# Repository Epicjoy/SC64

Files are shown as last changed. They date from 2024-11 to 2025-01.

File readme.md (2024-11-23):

# SummerCart64 - a fully open source N64 flashcart

This project's hardware and casing are modified based on the [SummerCart64](https://github.com/Polprzewodnikowy/SummerCart64) project.

### Description

Experience classic gaming in a new way! SummerCart64 is a fully open-source flash cartridge designed for the Nintendo 64 (N64), perfect for both gamers and developers. Whether you want to relive your childhood memories or develop your own homebrew games, SummerCart64 has you covered.

### Features

-   **Extremely high game compatibility:** Supports N64 games up to 64MB (512Mb), covering the entire N64 game library
-  **Fast I/O**: Supports fast data transfer to ensure smooth gaming experiences，Thanks to a peak transfer rate of approximately 23.8 MiB/s, loading a maximum size game of **64MB** (512Mb) takes roughly 2.7 seconds under optimal conditions
- **RTC Functionality**: Built-in Real-Time Clock (**RTC**) to support games that require time functions.
-  **High-Capacity SD Card Support**: Supports microSD cards up to 2TB, allowing you to store more games and files.
-  **64DD Hardware Emulation**: It can play disk dumps directly! Combo games (N64 cartridge + 64DD disk) and multi-disk 64DD games are also supported.
- **Automatic Save Backup**: Automatically backs up saves during gameplay to protect your progress.
-  **Multi-Region Support**: Compatible with all region N64 consoles, eliminating region lock concerns.
-  **Enough space for your ROMs**: Equipped with **64 MiB SDRAM** and **16 MiB flash** memory to ensure smooth game operation.
-  **Easy Game Management**: Browse, run, and manage your game library directly on your N64 console with the intuitive N64FlashcartMenu.
-  **Full control of boot process:** perfect for trying out custom **IPL3** replacements giving you control right after N64 boots up

### Example

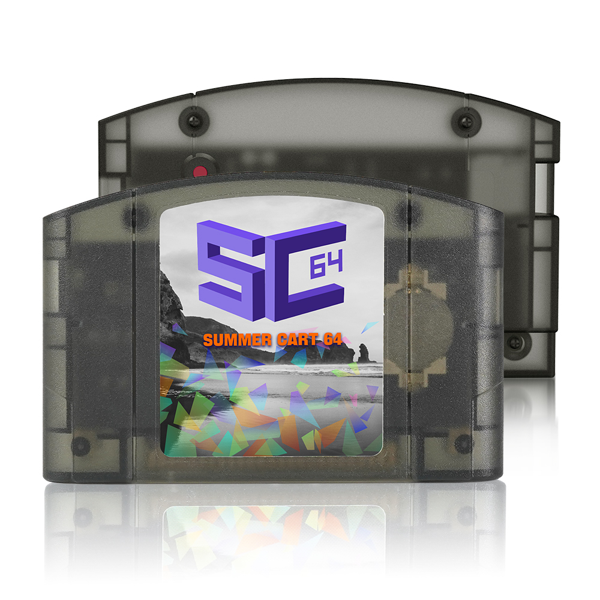
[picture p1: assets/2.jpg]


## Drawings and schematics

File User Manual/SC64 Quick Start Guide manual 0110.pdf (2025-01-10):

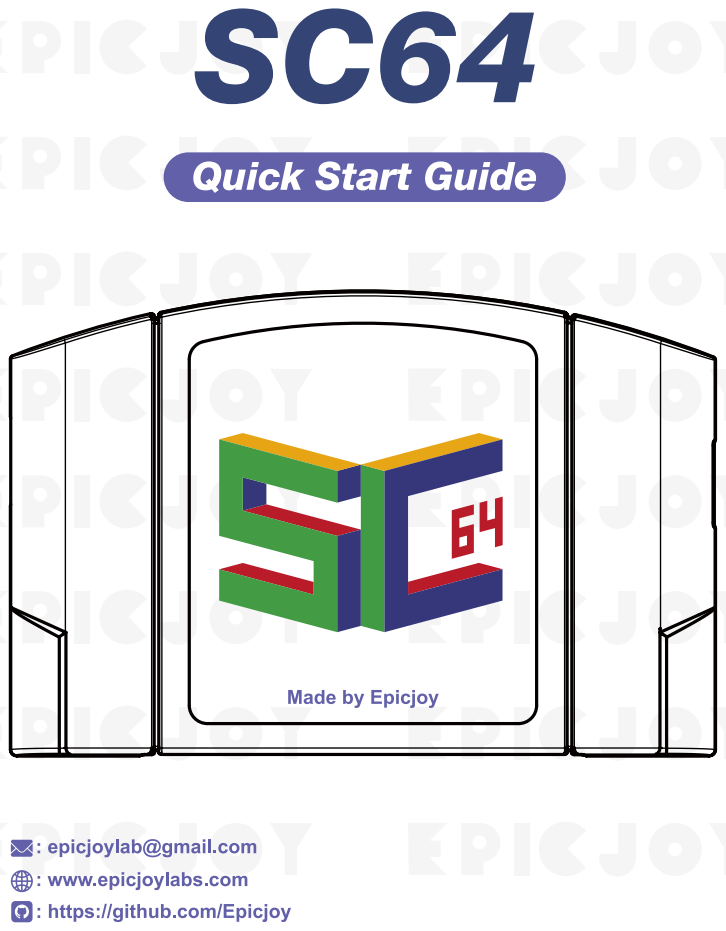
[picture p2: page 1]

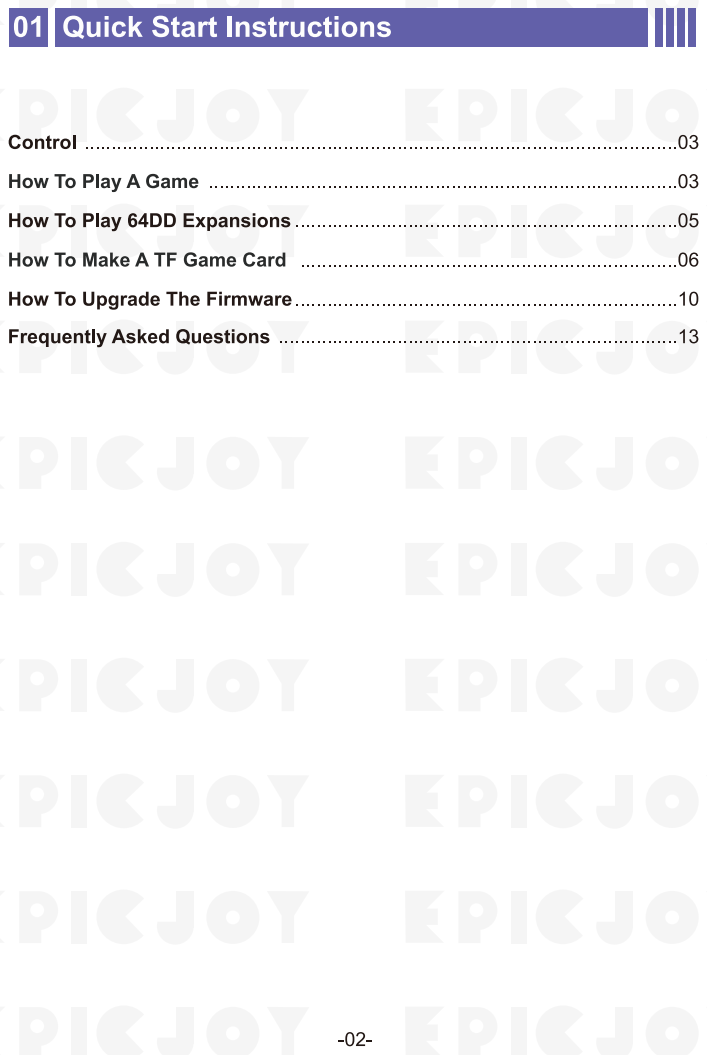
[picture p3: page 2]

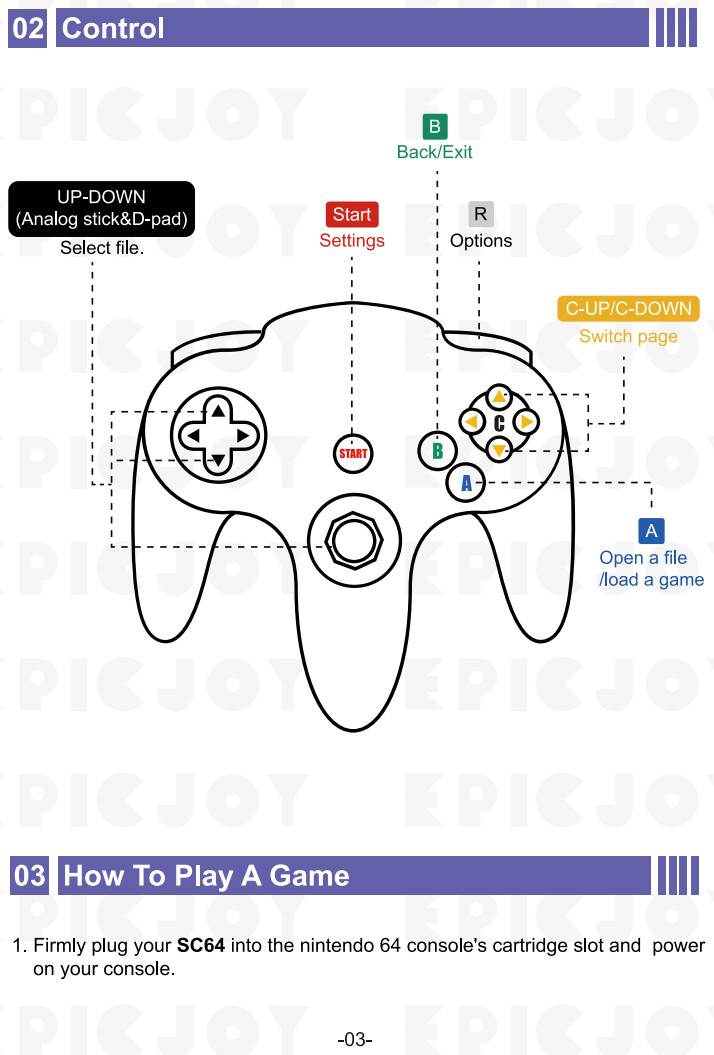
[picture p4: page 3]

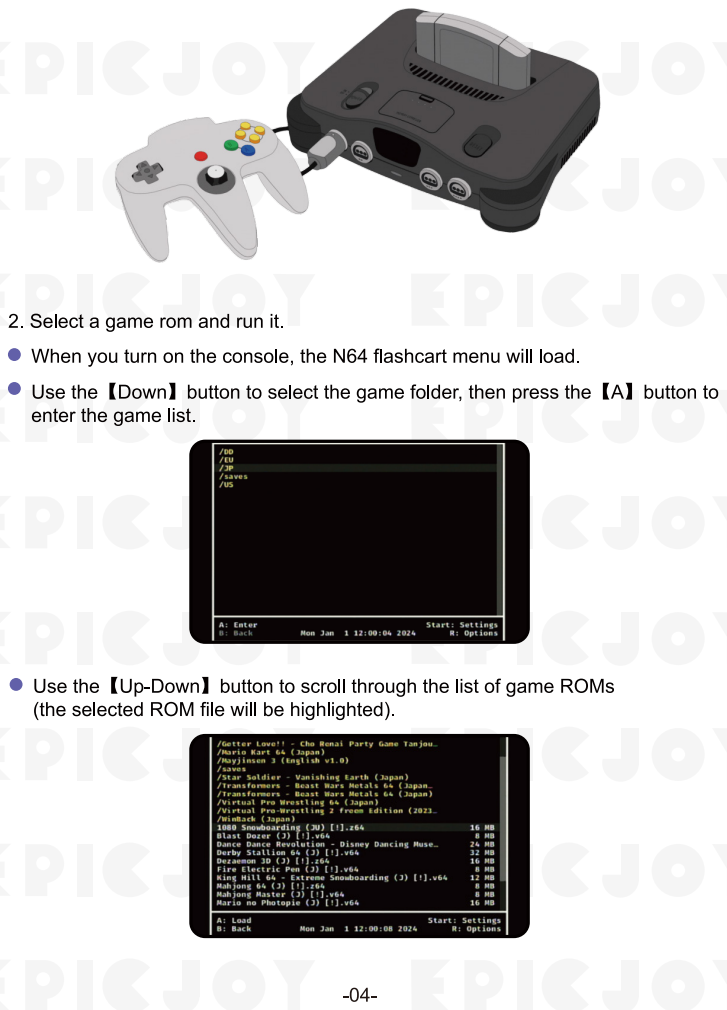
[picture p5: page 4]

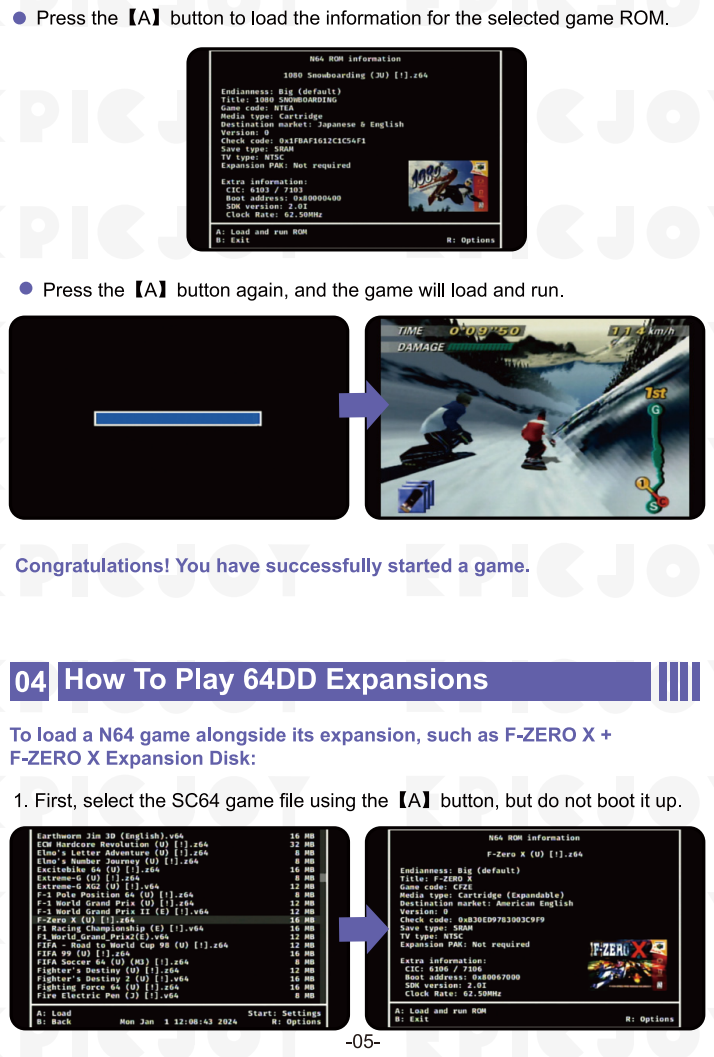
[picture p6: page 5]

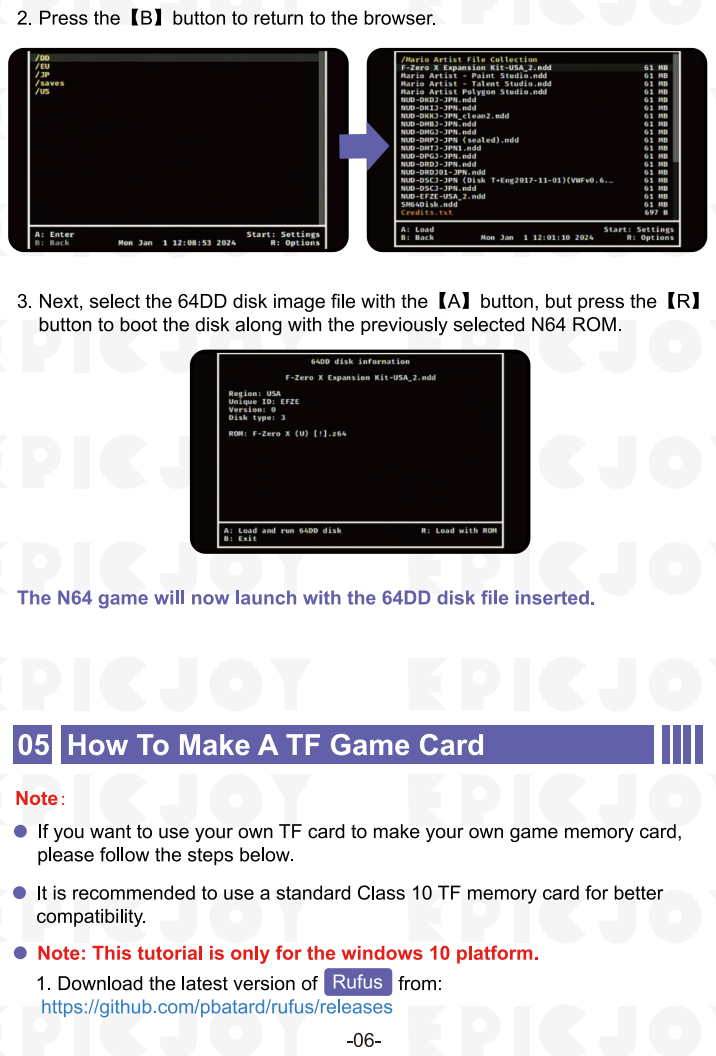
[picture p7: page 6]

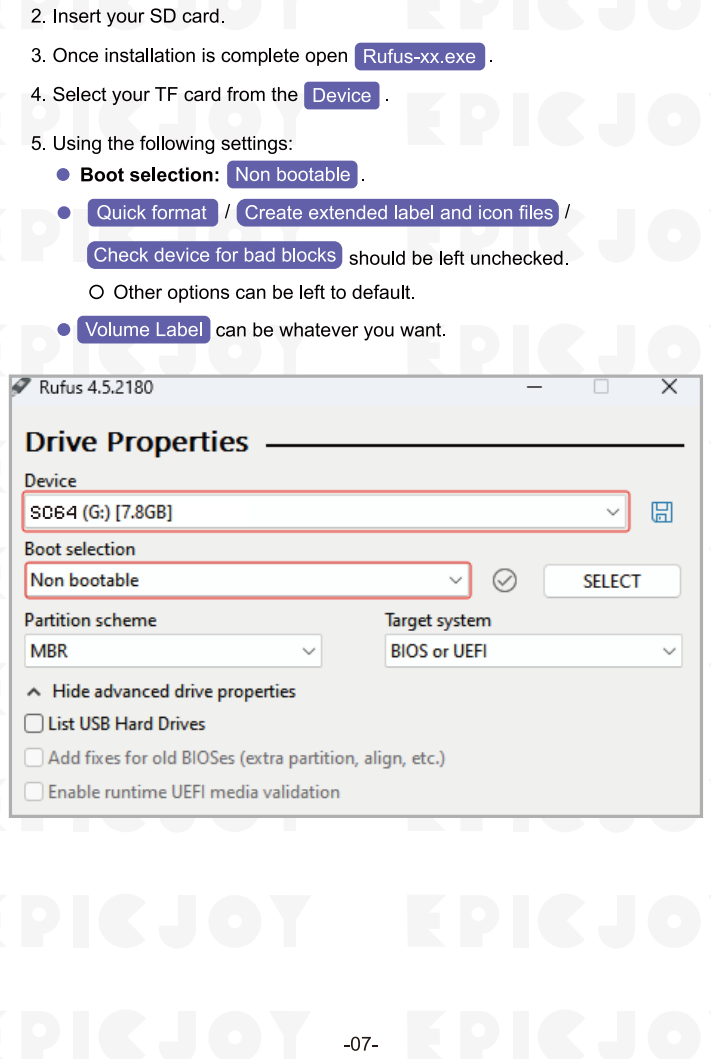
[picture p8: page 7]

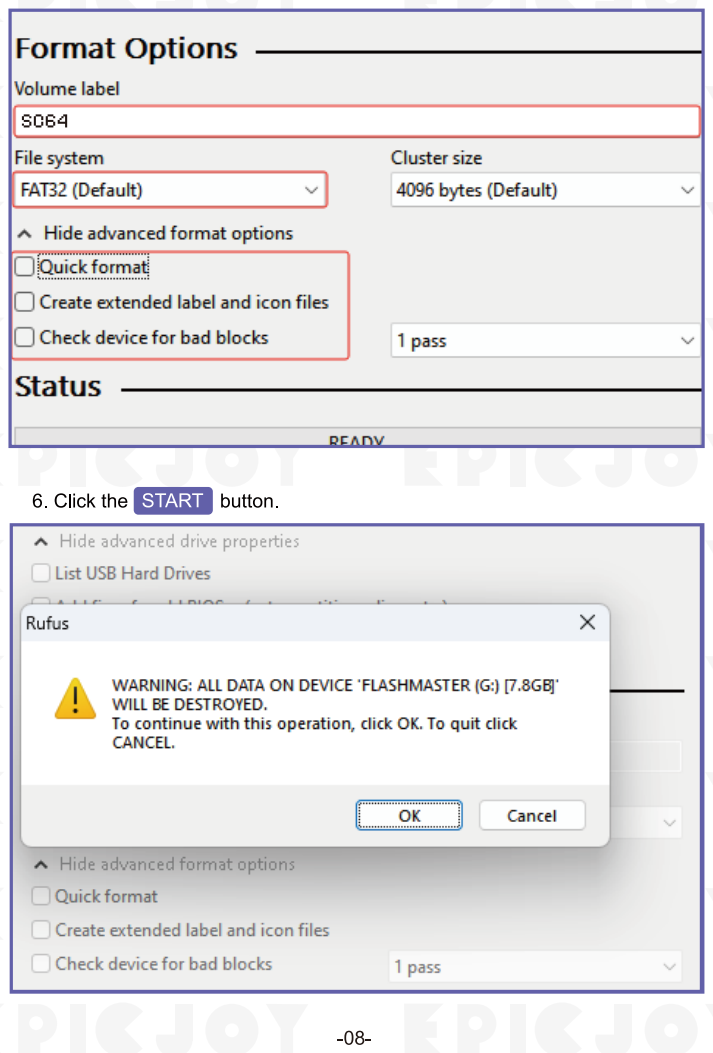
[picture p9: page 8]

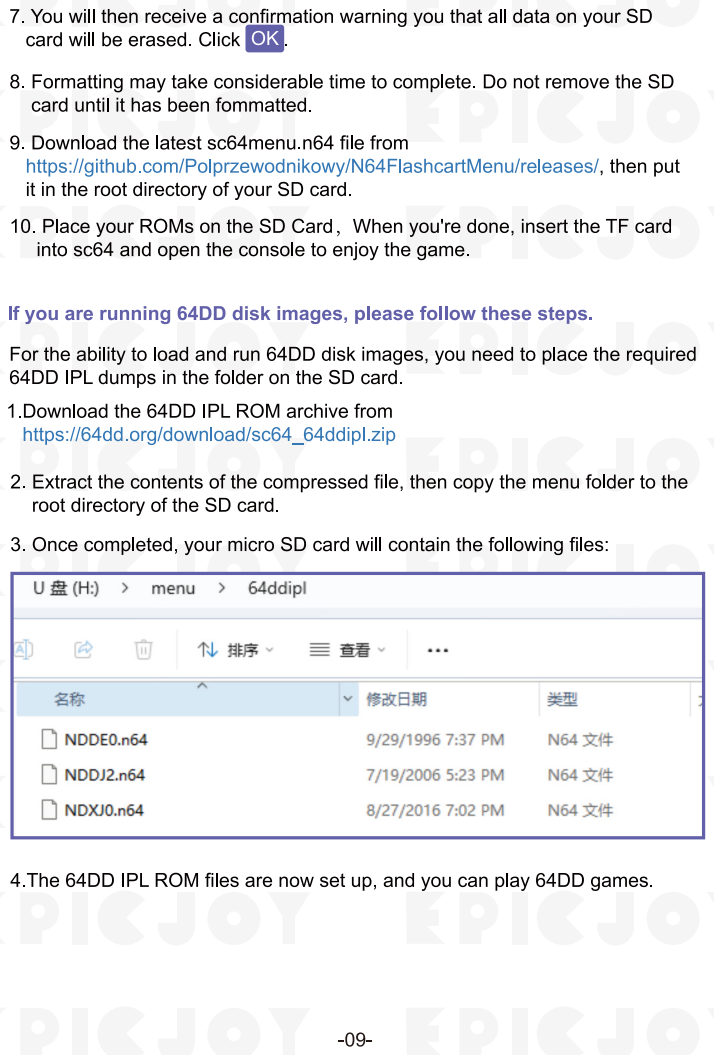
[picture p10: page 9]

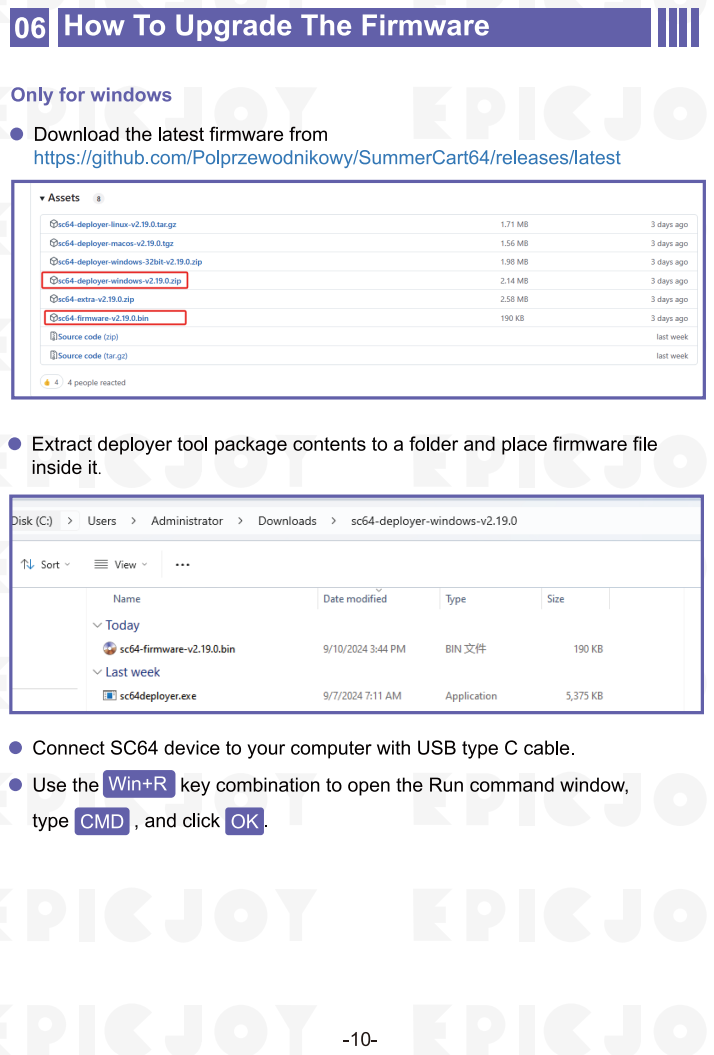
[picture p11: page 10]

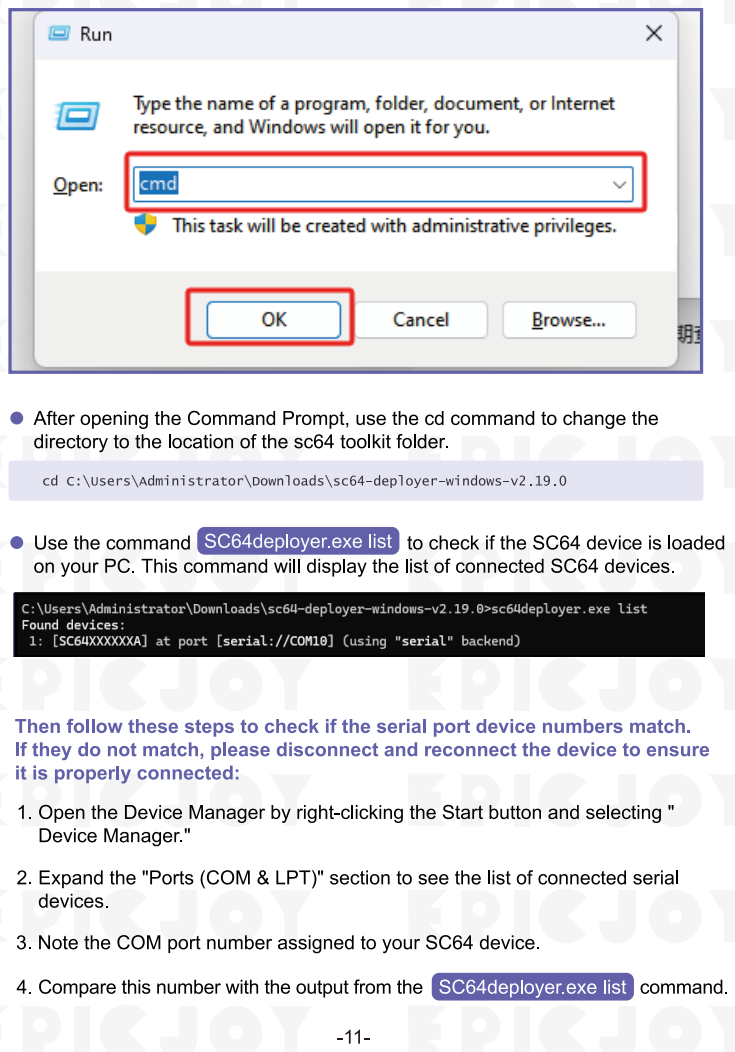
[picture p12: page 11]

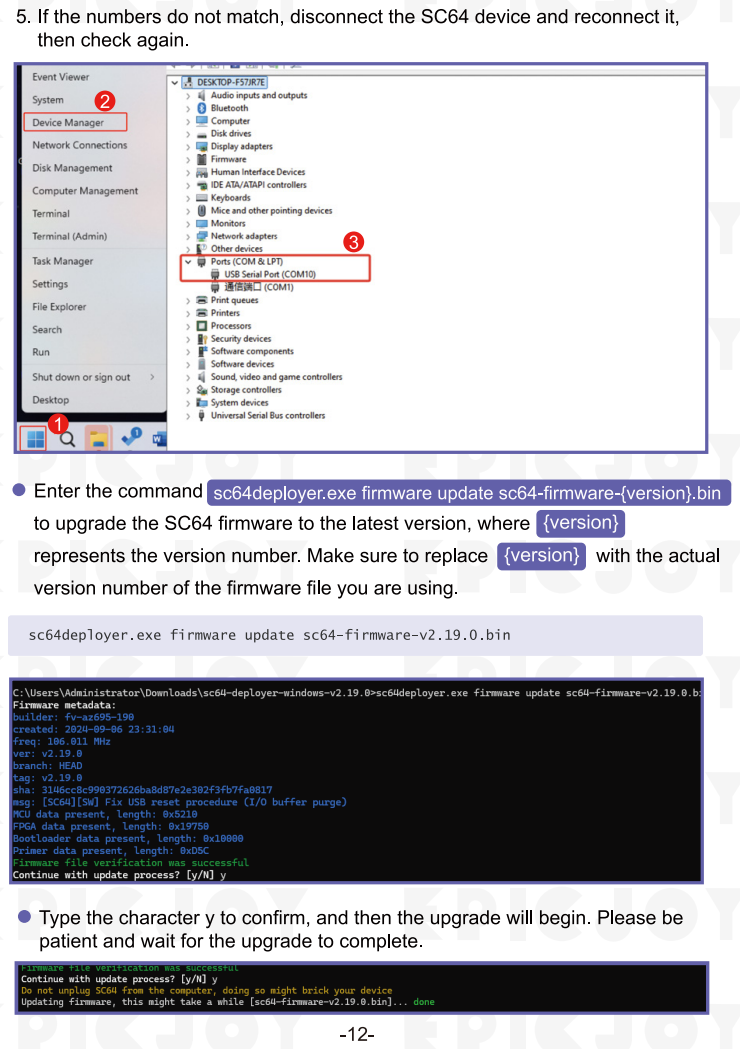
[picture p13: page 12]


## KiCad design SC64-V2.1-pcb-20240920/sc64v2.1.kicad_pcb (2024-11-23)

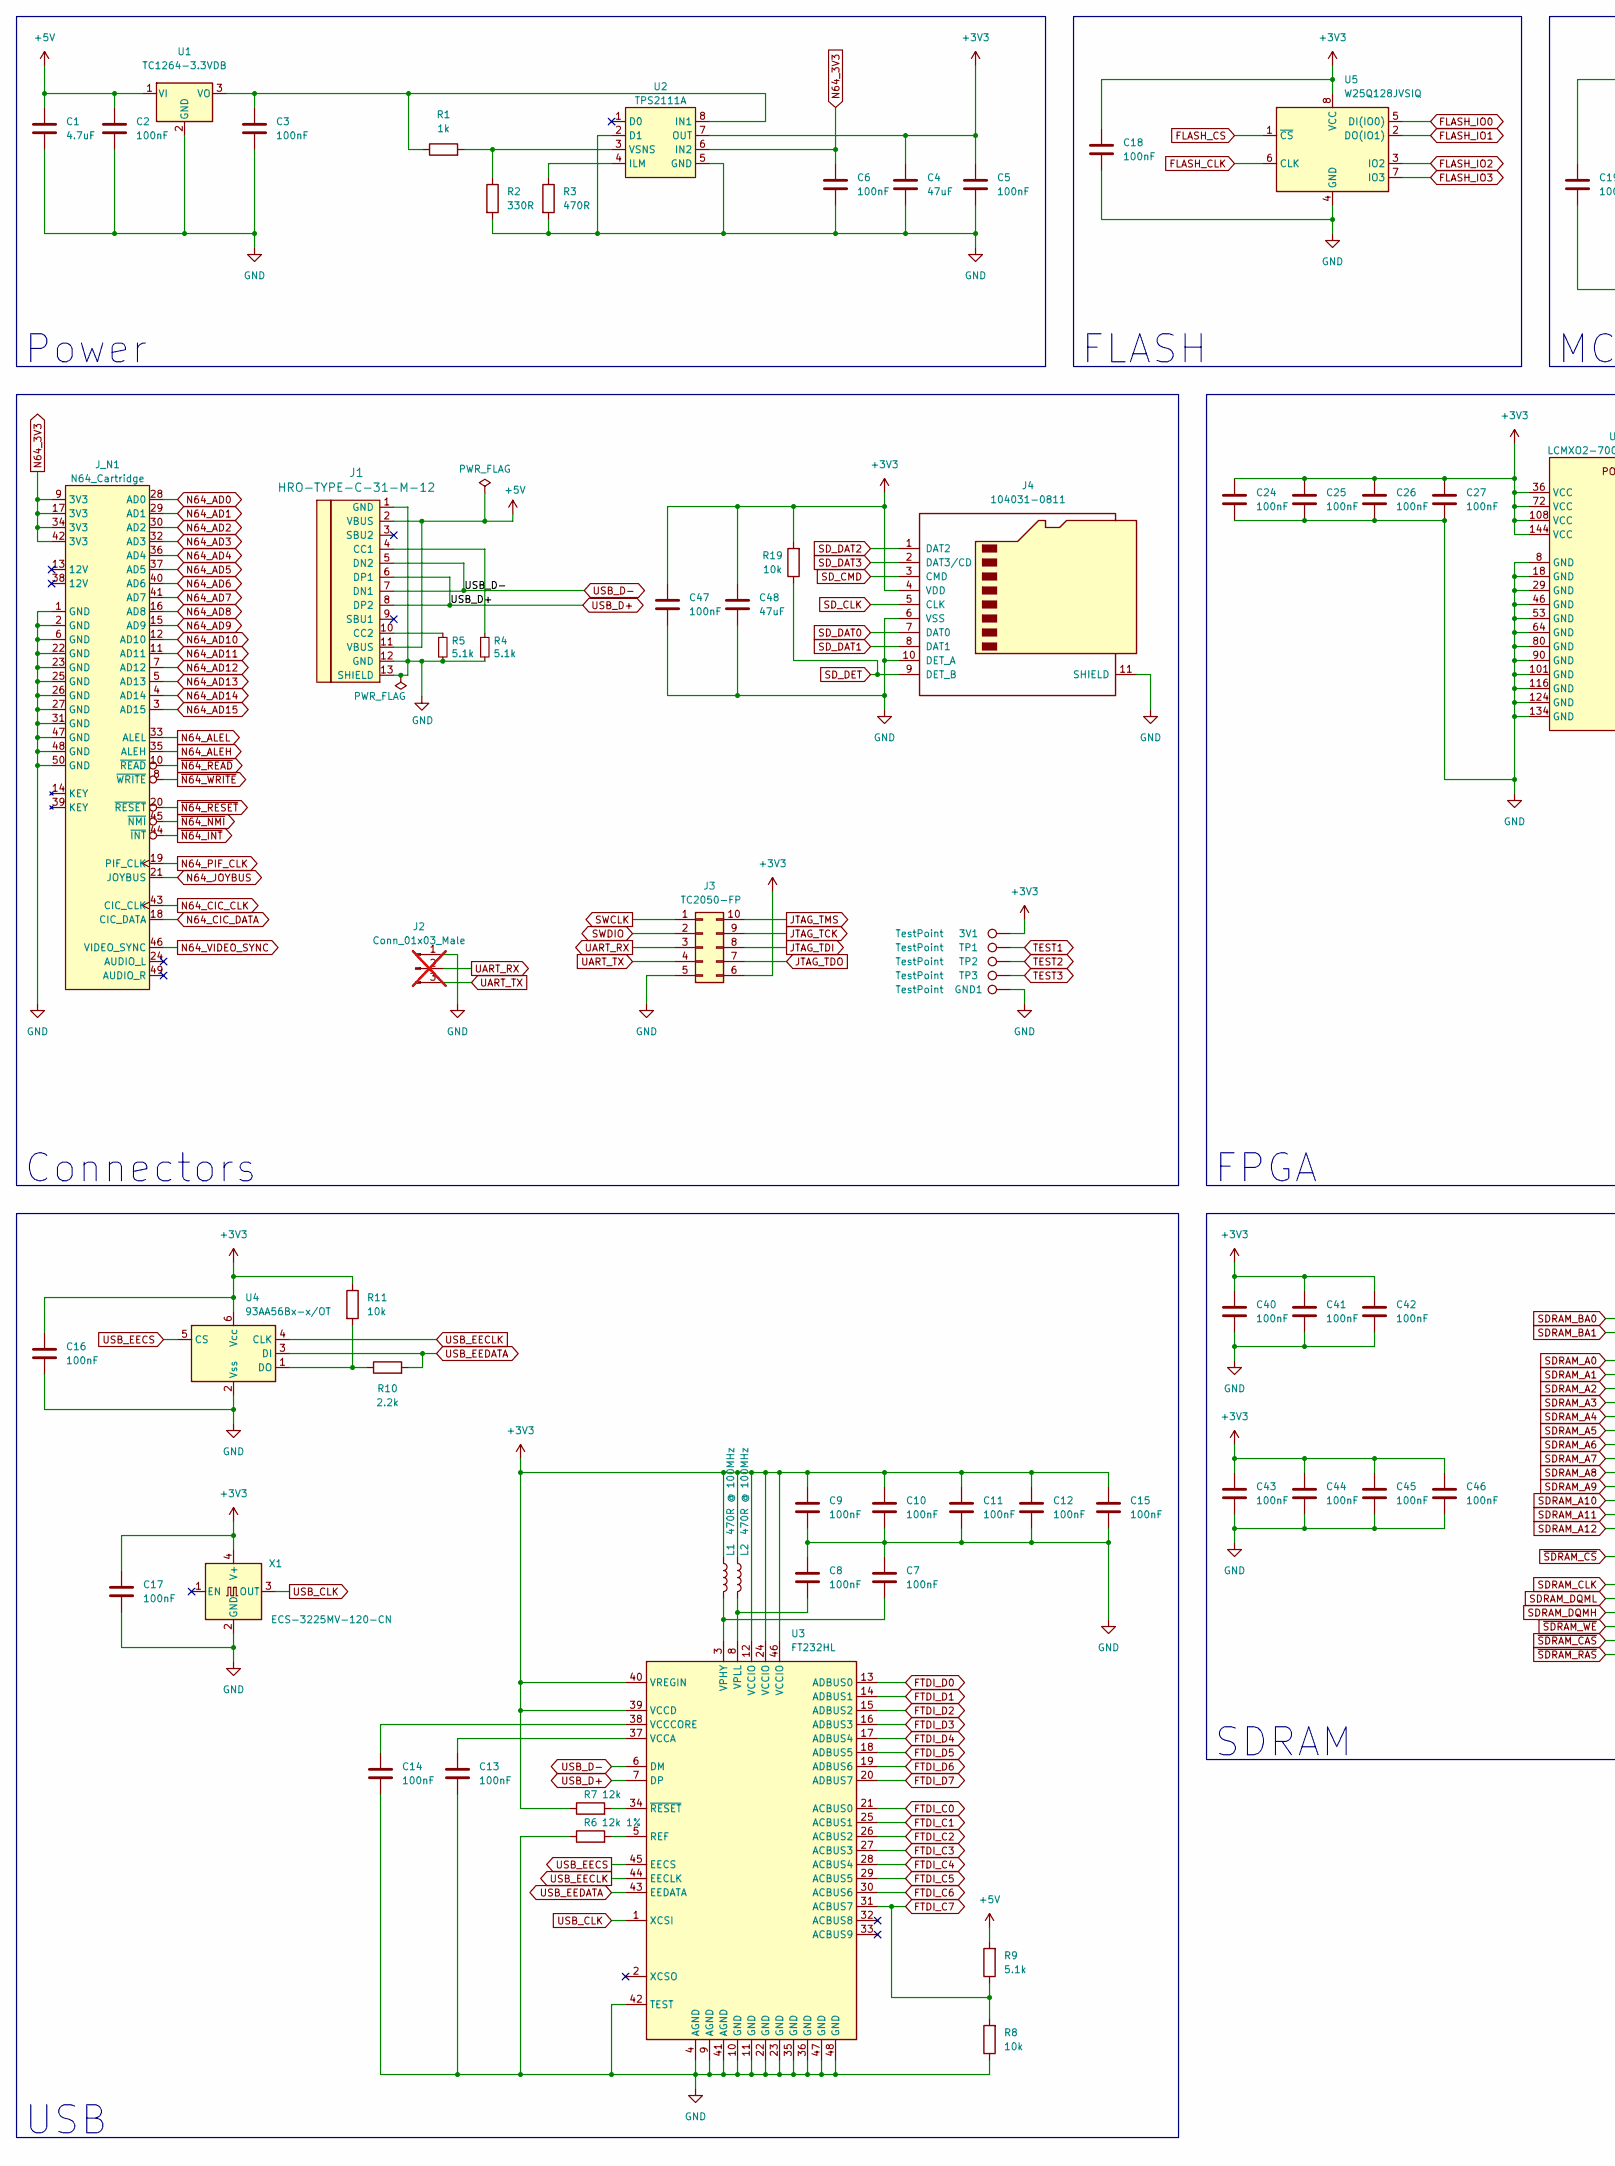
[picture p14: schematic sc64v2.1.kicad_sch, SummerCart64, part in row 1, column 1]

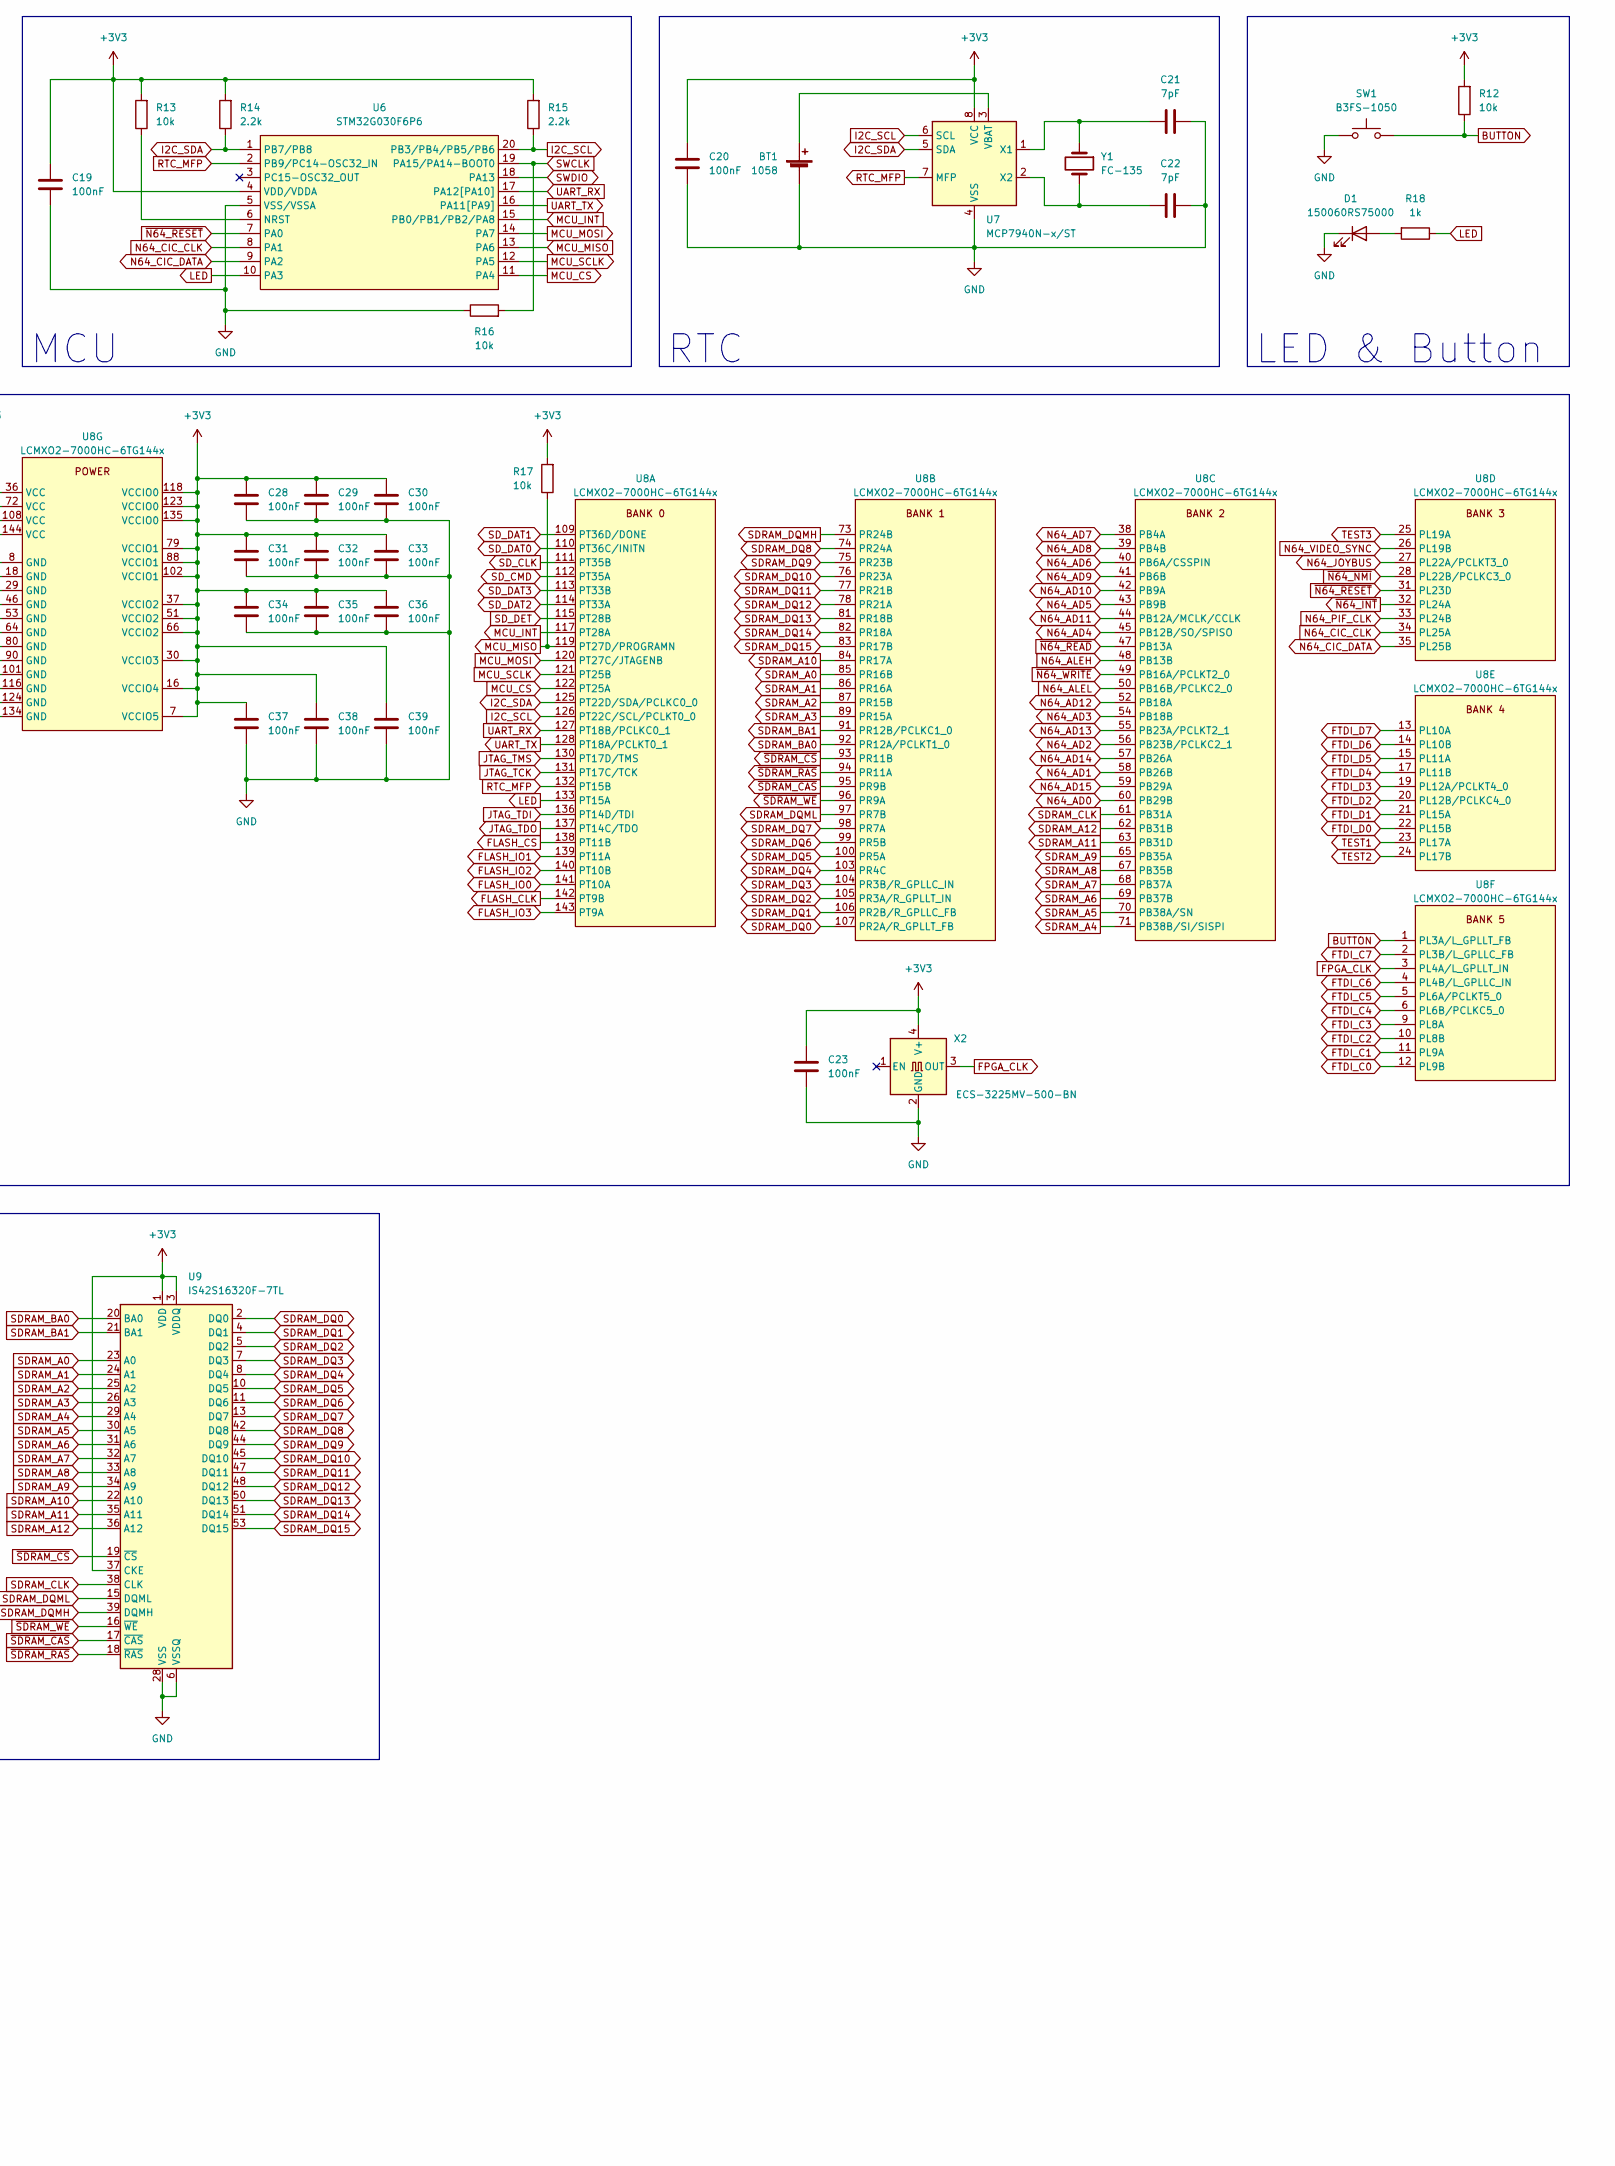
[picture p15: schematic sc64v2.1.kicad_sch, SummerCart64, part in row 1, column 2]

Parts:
3V1: TestPoint; TestPoint_Pad_D1.5mm
BT1: 1058; BatteryHolder_Keystone_1058_1x2032
C1: 4.7uF; C_0603_1608Metric
C2, C3, C5, C6, C7, C8, C9, C10, C11, C12, C13, C14, C15, C16, C17, C18, C19, C20, C23, C24, C25, C26, C27, C28, C29, C30, C31, C32, C33, C34, C35, C36, C37, C38, C39, C40, C41, C42, C43, C44, C45, C46, C47: 100nF; C_0603_1608Metric
C4, C48: 47uF; C_0805_2012Metric
C21, C22: 7pF; C_0603_1608Metric
D1: 150060RS75000; LED_0603_1608Metric
GND1: TestPoint; TestPoint_Pad_D1.5mm
J1: HRO-TYPE-C-31-M-12; HRO-TYPE-C-31-M-12-Assembly; LCSC C165948
J2: Conn_01x03_Male; PinHeader_1x03_P2.54mm_Vertical; not fitted
J3: TC2050-FP; Tag-Connect_TC2050-IDC-FP_2x05_P1.27mm_Vertical
J4: 104031-0811; microSD_HC_Molex_104031-0811
J_N1: N64_Cartridge; N64_Edge
L1, L2: 470R @ 100MHz; L_0603_1608Metric
R1, R18: 1k; R_0603_1608Metric
R2: 330R; R_0603_1608Metric
R3: 470R; R_0603_1608Metric
R4, R5: 5.1k; R_0603_1608Metric; LCSC C25905
R6: 12k 1%; R_0603_1608Metric
R7: 12k; R_0603_1608Metric
R8, R11, R12, R13, R16, R17, R19: 10k; R_0603_1608Metric
R9: 5.1k; R_0603_1608Metric
R10, R14, R15: 2.2k; R_0603_1608Metric
SW1: B3FS-1050; SW_SPST_Omron_B3FS-105xP
TP1, TP2, TP3: TestPoint; TestPoint_Pad_D1.5mm
U1: TC1264-3.3VDB; SOT-223-3_TabPin2
U2: TPS2111A; TSSOP-8_4.4x3mm_P0.65mm
U3: FT232HL; LQFP-48_7x7mm_P0.5mm
U4: 93AA56Bx-x/OT; SOT-23-6
U5: W25Q128JVSIQ; SOIC-8_5.23x5.23mm_P1.27mm
U6: STM32G030F6P6; TSSOP-20_4.4x6.5mm_P0.65mm
U7: MCP7940N-x/ST; TSSOP-8_4.4x3mm_P0.65mm
U8: LCMXO2-7000HC-6TG144x; TQFP-144_20x20mm_P0.5mm
U9: IS42S16320F-7TL; TSOP-II-54_22.2x10.16mm_P0.8mm
X1: ECS-3225MV-120-CN; Oscillator_SMD_SeikoEpson_SG8002CE-4Pin_3.2x2.5mm
X2: ECS-3225MV-500-BN; Oscillator_SMD_SeikoEpson_SG8002CE-4Pin_3.2x2.5mm
Y1: FC-135; Crystal_SMD_3215-2Pin_3.2x1.5mm

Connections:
+3V3: 3V1.1, C4.1, C5.1, C9.1, C10.1, C11.1, C12.1, C15.1, C16.2, C17.1, C18.1, C19.1, C20.1, C23.1, C24.1, C25.1, C26.1, C27.1, C28.1, C29.1, C30.1, C31.1, C32.1, C33.1, C34.1, C35.1, C36.1, C37.1, C38.1, C39.1, C40.1, C41.1, C42.1, C43.1, C44.1, C45.1, C46.1, C47.1, C48.1, J3.6, J4.4 (VDD), L1.1, L2.1, R7.1, R11.1, R12.2, R13.2, R14.2, R15.2, R17.2, R19.2, U2.7 (OUT), U3.12 (VCCIO), U3.24 (VCCIO), U3.39 (VCCD), U3.40 (VREGIN), U3.46 (VCCIO), U4.6 (Vсс), U5.8 (VCC), U6.4 (VDD/VDDA), U7.8 (VCC), U8.7 (VCCIO5), U8.16 (VCCIO4), U8.30 (VCCIO3), U8.36 (VCC), U8.37 (VCCIO2), U8.51 (VCCIO2), U8.66 (VCCIO2), U8.72 (VCC), U8.79 (VCCIO1), U8.88 (VCCIO1), U8.102 (VCCIO1), U8.108 (VCC), U8.118 (VCCIO0), U8.123 (VCCIO0), U8.135 (VCCIO0), U8.144 (VCC), U9.1 (VDD), U9.3 (VDDQ), U9.9 (VDDQ), U9.14 (VDD), U9.27 (VDD), U9.37 (CKE), U9.43 (VDDQ), U9.49 (VDDQ), X1.4 (V+), X2.4 (V+)
+5V: C1.1, C2.1, J1.2 (VBUS), J1.11 (VBUS), R9.2, U1.1 (VI)
BUTTON: R12.1, SW1.2, U8.1 (PL3A/L_GPLLT_FB)
FLASH_CLK: U5.6 (CLK), U8.142 (PT9B)
FLASH_CS: U5.1 (~CS), U8.138 (PT11B)
FLASH_IO0: U5.5 (DI(IO0)), U8.141 (PT10A)
FLASH_IO1: U5.2 (DO(IO1)), U8.139 (PT11A)
FLASH_IO2: U5.3 (IO2), U8.140 (PT10B)
FLASH_IO3: U5.7 (IO3), U8.143 (PT9A)
FPGA_CLK: U8.3 (PL4A/L_GPLLT_IN), X2.3 (OUT)
FTDI_C0: U3.21 (ACBUS0), U8.12 (PL9B)
FTDI_C1: U3.25 (ACBUS1), U8.11 (PL9A)
FTDI_C2: U3.26 (ACBUS2), U8.10 (PL8B)
FTDI_C3: U3.27 (ACBUS3), U8.9 (PL8A)
FTDI_C4: U3.28 (ACBUS4), U8.6 (PL6B/PCLKC5_0)
FTDI_C5: U3.29 (ACBUS5), U8.5 (PL6A/PCLKT5_0)
FTDI_C6: U3.30 (ACBUS6), U8.4 (PL4B/L_GPLLC_IN)
FTDI_C7: R8.2, R9.1, U3.31 (ACBUS7), U8.2 (PL3B/L_GPLLC_FB)
FTDI_D0: U3.13 (ADBUS0), U8.22 (PL15B)
FTDI_D1: U3.14 (ADBUS1), U8.21 (PL15A)
FTDI_D2: U3.15 (ADBUS2), U8.20 (PL12B/PCLKC4_0)
FTDI_D3: U3.16 (ADBUS3), U8.19 (PL12A/PCLKT4_0)
FTDI_D4: U3.17 (ADBUS4), U8.17 (PL11B)
FTDI_D5: U3.18 (ADBUS5), U8.15 (PL11A)
FTDI_D6: U3.19 (ADBUS6), U8.14 (PL10B)
FTDI_D7: U3.20 (ADBUS7), U8.13 (PL10A)
GND: BT1.2 (-), C1.2, C2.2, C3.2, C4.2, C5.2, C6.2, C7.1, C8.2, C9.2, C10.2, C11.2, C12.2, C13.1, C14.1, C15.2, C16.1, C17.2, C18.2, C19.2, C20.2, C21.2, C22.1, C23.2, C24.2, C25.2, C26.2, C27.2, C28.2, C29.2, C30.2, C31.2, C32.2, C33.2, C34.2, C35.2, C36.2, C37.2, C38.2, C39.2, C40.2, C41.2, C42.2, C43.2, C44.2, C45.2, C46.2, C47.2, C48.2, D1.1 (K), GND1.1, J1.1 (GND), J1.12 (GND), J1.13 (SHIELD), J2.1, J3.5, J4.6 (VSS), J4.10 (DET_A), J4.11 (SHIELD), J4.12, J4.13, J_N1.1 (GND), J_N1.2 (GND), J_N1.6 (GND), J_N1.22 (GND), J_N1.23 (GND), J_N1.25 (GND), J_N1.26 (GND), J_N1.27 (GND), J_N1.31 (GND), J_N1.47 (GND), J_N1.48 (GND), J_N1.50 (GND), R2.2, R3.2, R4.2, R5.2, R6.1, R8.1, R16.1, SW1.1, U1.2 (GND), U2.2 (D1), U2.5 (GND), U3.4 (AGND), U3.9 (AGND), U3.10 (GND), U3.11 (GND), U3.22 (GND), U3.23 (GND), U3.35 (GND), U3.36 (GND), U3.41 (AGND), U3.42 (TEST), U3.47 (GND), U3.48 (GND), U4.2 (Vss), U5.4 (GND), U6.5 (VSS/VSSA), U7.4 (VSS), U8.8 (GND), U8.18 (GND), U8.29 (GND), U8.46 (GND), U8.53 (GND), U8.64 (GND), U8.80 (GND), U8.90 (GND), U8.101 (GND), U8.116 (GND), U8.124 (GND), U8.134 (GND), U9.6 (VSSQ), U9.12 (VSSQ), U9.28 (VSS), U9.41 (VSS), U9.46 (VSSQ), U9.52 (VSSQ), U9.54 (VSS), X1.2 (GND), X2.2 (GND)
I2C_SCL: R15.1, U6.20 (PB3/PB4/PB5/PB6), U7.6 (SCL), U8.126 (PT22C/SCL/PCLKT0_0)
I2C_SDA: R14.1, U6.1 (PB7/PB8), U7.5 (SDA), U8.125 (PT22D/SDA/PCLKC0_0)
JTAG_TCK: J3.9, U8.131 (PT17C/TCK)
JTAG_TDI: J3.8, U8.136 (PT14D/TDI)
JTAG_TDO: J3.7, U8.137 (PT14C/TDO)
JTAG_TMS: J3.10, U8.130 (PT17D/TMS)
LED: R18.1, U6.10 (PA3), U8.133 (PT15A)
MCU_CS: U6.11 (PA4), U8.122 (PT25A)
MCU_INT: U6.15 (PB0/PB1/PB2/PA8), U8.117 (PT28A)
MCU_MISO: R17.1, U6.13 (PA6), U8.119 (PT27D/PROGRAMN)
MCU_MOSI: U6.14 (PA7), U8.120 (PT27C/JTAGENB)
MCU_SCLK: U6.12 (PA5), U8.121 (PT25B)
N64_3V3: C6.1, J_N1.9 (3V3), J_N1.17 (3V3), J_N1.34 (3V3), J_N1.42 (3V3), U2.6 (IN2)
N64_AD0: J_N1.28 (AD0), U8.60 (PB29B)
N64_AD1: J_N1.29 (AD1), U8.58 (PB26B)
N64_AD2: J_N1.30 (AD2), U8.56 (PB23B/PCLKC2_1)
N64_AD3: J_N1.32 (AD3), U8.54 (PB18B)
N64_AD4: J_N1.36 (AD4), U8.45 (PB12B/SO/SPISO)
N64_AD5: J_N1.37 (AD5), U8.43 (PB9B)
N64_AD6: J_N1.40 (AD6), U8.40 (PB6A/CSSPIN)
N64_AD7: J_N1.41 (AD7), U8.38 (PB4A)
N64_AD8: J_N1.16 (AD8), U8.39 (PB4B)
N64_AD9: J_N1.15 (AD9), U8.41 (PB6B)
N64_AD10: J_N1.12 (AD10), U8.42 (PB9A)
N64_AD11: J_N1.11 (AD11), U8.44 (PB12A/MCLK/CCLK)
N64_AD12: J_N1.7 (AD12), U8.52 (PB18A)
N64_AD13: J_N1.5 (AD13), U8.55 (PB23A/PCLKT2_1)
N64_AD14: J_N1.4 (AD14), U8.57 (PB26A)
N64_AD15: J_N1.3 (AD15), U8.59 (PB29A)
N64_ALEH: J_N1.35 (ALEH), U8.48 (PB13B)
N64_ALEL: J_N1.33 (ALEL), U8.50 (PB16B/PCLKC2_0)
N64_CIC_CLK: J_N1.43 (CIC_CLK), U6.8 (PA1), U8.34 (PL25A)
N64_CIC_DATA: J_N1.18 (CIC_DATA), U6.9 (PA2), U8.35 (PL25B)
N64_JOYBUS: J_N1.21 (JOYBUS), U8.27 (PL22A/PCLKT3_0)
N64_PIF_CLK: J_N1.19 (PIF_CLK), U8.33 (PL24B)
N64_VIDEO_SYNC: J_N1.46 (VIDEO_SYNC), U8.26 (PL19B)
unnamed: BT1.1 (+), U7.3 (VBAT)
unnamed: D1.2 (A), R18.2
unnamed: C3.1, R1.1, U1.3 (VO), U2.8 (IN1)
unnamed: R3.1, U2.4 (ILM)
unnamed: R1.2, R2.1, U2.3 (VSNS)
unnamed: R6.2, U3.5 (REF)
unnamed: C13.2, U3.37 (VCCA)
unnamed: C14.2, U3.38 (VCCCORE)
unnamed: C7.2, L1.2, U3.3 (VPHY)
unnamed: C8.1, L2.2, U3.8 (VPLL)
unnamed: R7.2, U3.34 (~RESET)
unnamed: R10.1, R11.2, U4.1 (DO)
unnamed: R13.1, U6.6 (NRST)
unnamed: C21.1, U7.1 (X1), Y1.1
unnamed: C22.2, U7.2 (X2), Y1.2
unnamed: J1.4 (CC1), R4.1
unnamed: J1.10 (CC2), R5.1
RTC_MFP: U6.2 (PB9/PC14-OSC32_IN), U7.7 (MFP), U8.132 (PT15B)
SDRAM_A0: U8.85 (PR16B), U9.23 (A0)
SDRAM_A1: U8.86 (PR16A), U9.24 (A1)
SDRAM_A2: U8.87 (PR15B), U9.25 (A2)
SDRAM_A3: U8.89 (PR15A), U9.26 (A3)
SDRAM_A4: U8.71 (PB38B/SI/SISPI), U9.29 (A4)
SDRAM_A5: U8.70 (PB38A/SN), U9.30 (A5)
SDRAM_A6: U8.69 (PB37B), U9.31 (A6)
SDRAM_A7: U8.68 (PB37A), U9.32 (A7)
SDRAM_A8: U8.67 (PB35B), U9.33 (A8)
SDRAM_A9: U8.65 (PB35A), U9.34 (A9)
SDRAM_A10: U8.84 (PR17A), U9.22 (A10)
SDRAM_A11: U8.63 (PB31D), U9.35 (A11)
SDRAM_A12: U8.62 (PB31B), U9.36 (A12)
SDRAM_BA0: U8.92 (PR12A/PCLKT1_0), U9.20 (BA0)
SDRAM_BA1: U8.91 (PR12B/PCLKC1_0), U9.21 (BA1)
SDRAM_CLK: U8.61 (PB31A), U9.38 (CLK)
SDRAM_DQ0: U8.107 (PR2A/R_GPLLT_FB), U9.2 (DQ0)
SDRAM_DQ1: U8.106 (PR2B/R_GPLLC_FB), U9.4 (DQ1)
SDRAM_DQ2: U8.105 (PR3A/R_GPLLT_IN), U9.5 (DQ2)
SDRAM_DQ3: U8.104 (PR3B/R_GPLLC_IN), U9.7 (DQ3)
SDRAM_DQ4: U8.103 (PR4C), U9.8 (DQ4)
SDRAM_DQ5: U8.100 (PR5A), U9.10 (DQ5)
SDRAM_DQ6: U8.99 (PR5B), U9.11 (DQ6)
SDRAM_DQ7: U8.98 (PR7A), U9.13 (DQ7)
SDRAM_DQ8: U8.74 (PR24A), U9.42 (DQ8)
SDRAM_DQ9: U8.75 (PR23B), U9.44 (DQ9)
SDRAM_DQ10: U8.76 (PR23A), U9.45 (DQ10)
SDRAM_DQ11: U8.77 (PR21B), U9.47 (DQ11)
SDRAM_DQ12: U8.78 (PR21A), U9.48 (DQ12)
SDRAM_DQ13: U8.81 (PR18B), U9.50 (DQ13)
SDRAM_DQ14: U8.82 (PR18A), U9.51 (DQ14)
SDRAM_DQ15: U8.83 (PR17B), U9.53 (DQ15)
SDRAM_DQMH: U8.73 (PR24B), U9.39 (DQMH)
SDRAM_DQML: U8.97 (PR7B), U9.15 (DQML)
SD_CLK: J4.5 (CLK), U8.111 (PT35B)
SD_CMD: J4.3 (CMD), U8.112 (PT35A)
SD_DAT0: J4.7 (DAT0), U8.110 (PT36C/INITN)
SD_DAT1: J4.8 (DAT1), U8.109 (PT36D/DONE)
SD_DAT2: J4.1 (DAT2), U8.114 (PT33A)
SD_DAT3: J4.2 (DAT3/CD), U8.113 (PT33B)
SD_DET: J4.9 (DET_B), R19.1, U8.115 (PT28B)
SWCLK: J3.1, R16.2, U6.19 (PA15/PA14-BOOT0)
SWDIO: J3.2, U6.18 (PA13)
TEST1: TP1.1, U8.23 (PL17A)
TEST2: TP2.1, U8.24 (PL17B)
TEST3: TP3.1, U8.25 (PL19A)
UART_RX: J2.2, J3.3, U6.17 (PA12[PA10]), U8.127 (PT18B/PCLKC0_1)
UART_TX: J2.3, J3.4, U6.16 (PA11[PA9]), U8.128 (PT18A/PCLKT0_1)
USB_CLK: U3.1 (XCSI), X1.3 (OUT)
USB_D+: J1.6 (DP1), J1.8 (DP2), U3.7 (DP)
USB_D-: J1.5 (DN2), J1.7 (DN1), U3.6 (DM)
USB_EECLK: U3.44 (EECLK), U4.4 (CLK)
USB_EECS: U3.45 (EECS), U4.5 (CS)
USB_EEDATA: R10.2, U3.43 (EEDATA), U4.3 (DI)
~N64_INT: J_N1.44 (~INT), U8.32 (PL24A)
~N64_NMI: J_N1.45 (~NMI), U8.28 (PL22B/PCLKC3_0)
~N64_READ: J_N1.10 (~READ), U8.47 (PB13A)
~N64_RESET: J_N1.20 (~RESET), U6.7 (PA0), U8.31 (PL23D)
~N64_WRITE: J_N1.8 (~WRITE), U8.49 (PB16A/PCLKT2_0)
~SDRAM_CAS: U8.95 (PR9B), U9.17 (~CAS)
~SDRAM_CS: U8.93 (PR11B), U9.19 (~CS)
~SDRAM_RAS: U8.94 (PR11A), U9.18 (~RAS)
~SDRAM_WE: U8.96 (PR9A), U9.16 (~WE)

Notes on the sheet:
Power
USB
LED & Button
RTC
Connectors
MCU
FPGA
FLASH
SDRAM

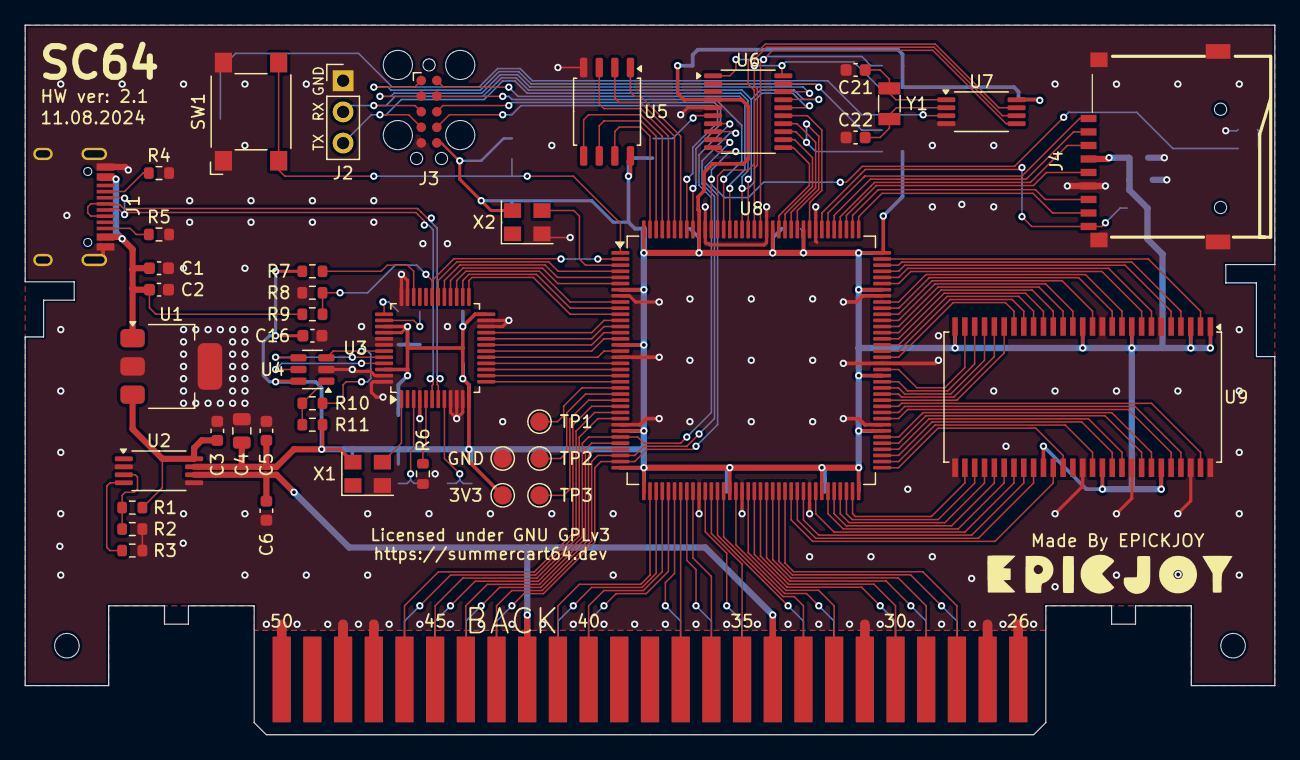
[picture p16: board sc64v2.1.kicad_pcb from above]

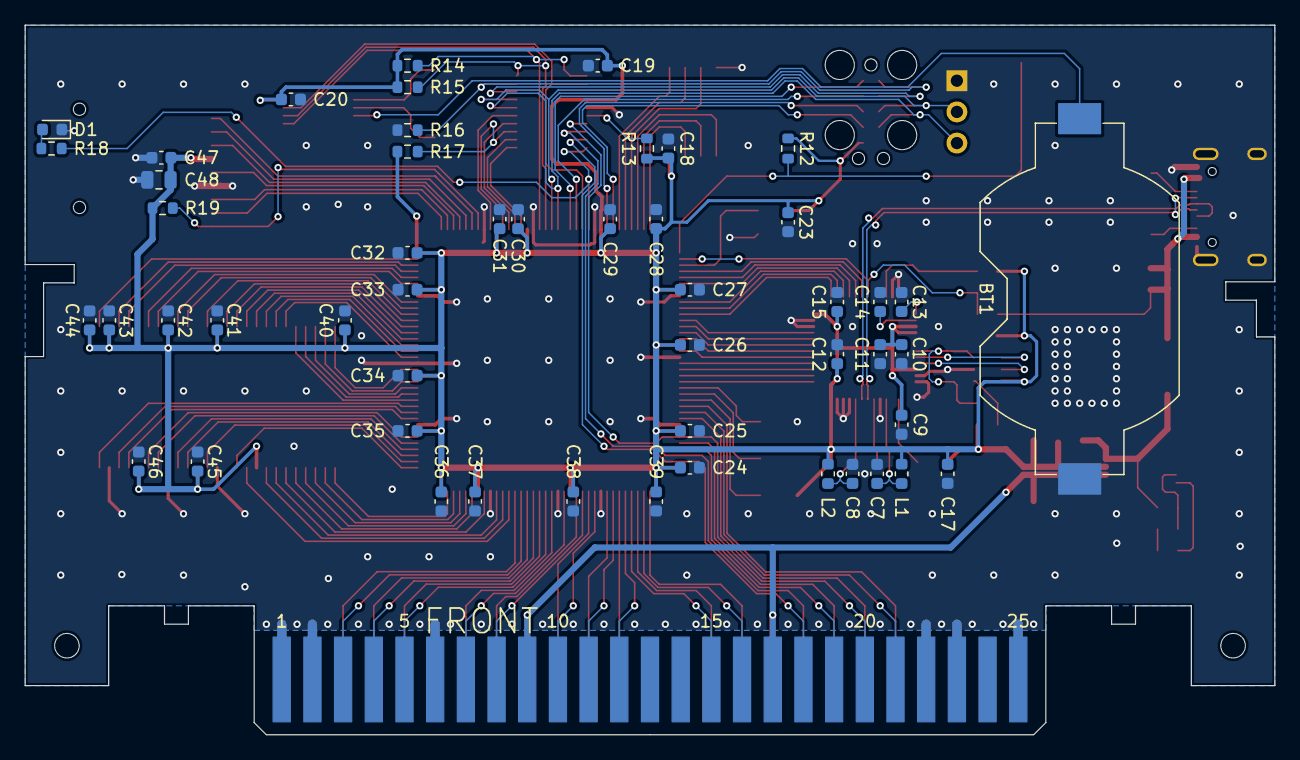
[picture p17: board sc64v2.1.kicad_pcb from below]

Board: 2 copper layers, 101.8 x 57.8 mm, 94 parts (51 on the bottom side), 144 nets.

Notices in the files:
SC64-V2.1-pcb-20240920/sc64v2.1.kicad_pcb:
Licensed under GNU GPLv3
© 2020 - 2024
